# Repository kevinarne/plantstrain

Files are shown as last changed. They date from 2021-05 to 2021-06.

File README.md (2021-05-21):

# Overview
I have a bit of an obsession with plants. This repository contains the work I've done to find ways to track one more piece of information about my plants: weight, or at least something proportional to weight. The theory is that I can identify two things from tracking weight over time: the growth of the plant itself and how much water is in the soil.

# Contents
* Schematic Files
* PCB Layout
* Arduino Sketches
  * Peripheral Sketch for ATTiny85
  * Controller Sketch for microcontroller of your choice

# Theory of Operation
The weight PCB features an integrated strain gauge in a Wheatstone Bridge configuration with a microcontroller (ATTiny85) that reads the voltage (using 10-bit ADC) at two points in the Wheatstone Bridge. The differences in those voltages is directly related to the change in resistance of the strain gauge, which in turn is directly related to the extension or compression of the strain gauge. The ATTiny85 acts as an I2C device with address 0x10 and sends both voltage values (as uint16_t's split into two bytes each) upon request.

# To Do
* The current PCB doesn't feature a current-limiting resistor for the Wheatstone Bridge as a whole, so I've bodged one in to my test board. A current limiting resistor pad should be added to the next spin of the board.
* Communication with the strain gauge board needs to be encapsulated in a class, much like in many Adafruit sensor libraries.
* The strain gauge needs testing and may need an ADC with higher resolution to resolve the small differences.
* I don't like the look of the current strain gauge and will likely tweak it to be more evenly spaced in the next board spin.
* It may make sense to use an internet-connected microcontroller (ESP32 or ESP8266) to store weight values in a remote database.

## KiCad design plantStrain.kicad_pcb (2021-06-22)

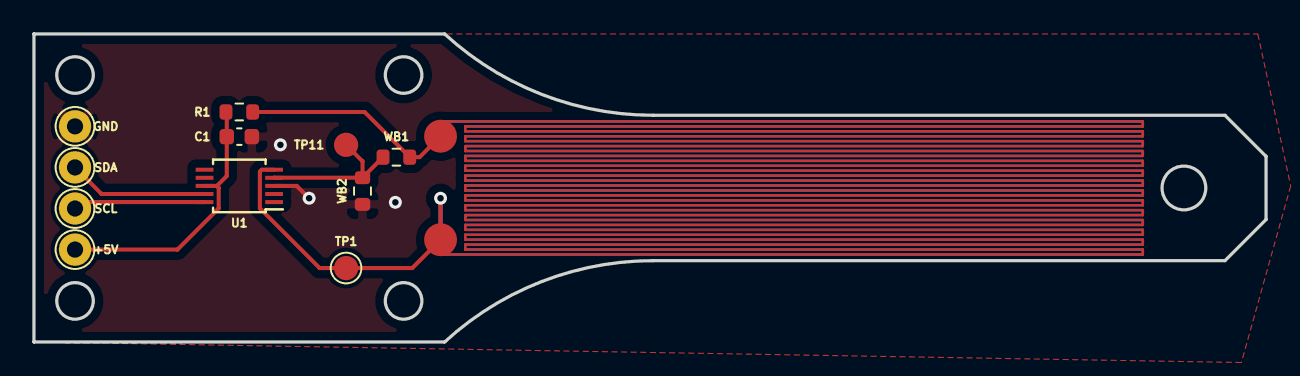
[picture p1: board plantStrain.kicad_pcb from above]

Board: 2 copper layers, 76.2 x 19.0 mm, 13 parts (1 on the bottom side), 7 nets.

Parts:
C1: CAP; C_0603_1608Metric
R1: 50; R_0603_1608Metric
SG1, SG2: Strain_Gauge; strainLonger
TP1: SG_WB; TestPoint_Pad_D1.5mm
TP7: 5V_I2C; TestPoint_THTPad_D2.0mm_Drill1.0mm
TP8: SDA_I2C; TestPoint_THTPad_D2.0mm_Drill1.0mm
TP9: SCL_I2C; TestPoint_THTPad_D2.0mm_Drill1.0mm
TP10: GND_I2C; TestPoint_THTPad_D2.0mm_Drill1.0mm
TP11: KNOWN_WB; TestPoint_Pad_D1.5mm
U1: ADS1015IDGS; TSSOP-10_3x3mm_P0.5mm
WB1, WB2: R_US; R_0603_1608Metric

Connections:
+5V: C1.1, R1.1, TP7.1, U1.8
GND: C1.2, SG2.2, TP10.1, U1.3, WB2.2
unnamed: R1.2, SG1.1, WB1.1
SCL: TP9.1, U1.10
SDA: TP8.1, U1.9
SG: SG1.2, SG2.1, TP1.1, U1.5
WB_REF: TP11.1, U1.4, WB1.2, WB2.1

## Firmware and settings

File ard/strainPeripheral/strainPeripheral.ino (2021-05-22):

#include <TinyWireS.h>

#define ITWOC_ADDR 16
#define WB_REF 4
#define WB_SG 3
#define LED_PIN 1

void setup() 
{
  //Set up I2C details
  TinyWireS.begin(ITWOC_ADDR);
  TinyWireS.onRequest(handleEvent);

  pinMode(WB_REF, INPUT);
  pinMode(WB_SG, INPUT);

  pinMode(LED_PIN, OUTPUT);
  digitalWrite(LED_PIN, LOW);
}

void loop() 
{
  //Kick your feet up and relax
}

void handleEvent() 
{
  digitalWrite(LED_PIN, HIGH);
  //Read both ADCs
  uint16_t ref = 1023; 
  uint16_t var = analogRead(WB_SG);

  //Temporary variable for sending data
  byte data[4];

  //These lines transform the uint16_t's into bytes for I2C transmission
  data[0] = (ref >> 8) & 0xFF;
  data[1] = ref & 0xFF;
  data[2] = (var >> 8) & 0xFF;
  data[3] = var & 0xFF;
  for(int i = 0; i < 4; i++)
  {
    TinyWireS.send(data[i]);
  }
  digitalWrite(LED_PIN, LOW);
}

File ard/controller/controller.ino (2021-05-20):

#include <Wire.h>

#define ITWOC_ADDR 16

void setup() 
{
  Wire.begin();
  Serial.begin(9600);
}

void loop() 
{
  //Request 1 byte from peripheral
  Wire.requestFrom(ITWOC_ADDR, 4);    
  if (Wire.available()) 
  {
    uint8_t val1 = Wire.read();
    uint8_t val2 = Wire.read();
    uint8_t val3 = Wire.read();
    uint8_t val4 = Wire.read();
    
    uint16_t ref = val1;
    ref = ref << 8 | val2;
    uint16_t wb_sg = val3;
    wb_sg = wb_sg << 8 | val4;

    Serial.print("Reference Value: ");
    Serial.println(ref);
    Serial.print("Strain Gauge Value: ");
    Serial.println(wb_sg);
  }
  delay(1000);
}

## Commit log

2021-05-20 Initial commit with first version of the strain PCB and Arduino code.
    [plantStrain.kicad_pcb, plantStrain.sch]
2021-05-22 Changed from Wire library to TinyWireS. Currently the device isn't responding to the controller at all, so more debugging will be needed.
2021-05-30 Modifying the PCB design to a half-bridge with longer strain-sensing units to improve the chance of noticing a change in resistance. Current-limiting resistor also added. In the process of switching 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
    [plantStrain.sch]
2021-06-03 Started updating the board for the strain gauge. Removed unused components and started placing the new ones. Next step is routing.
    [plantStrain.kicad_pcb, plantStrain.sch]
2021-06-06 Routed new board. Needs some more attention to the silkscreen layers to make it easy to use.
    [plantStrain.kicad_pcb]
2021-06-22 Second version of PCB sent to fab house.
    [plantStrain.kicad_pcb]
